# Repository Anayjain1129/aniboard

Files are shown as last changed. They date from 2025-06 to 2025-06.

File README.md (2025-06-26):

# Anay's Keyboard - Aniboard

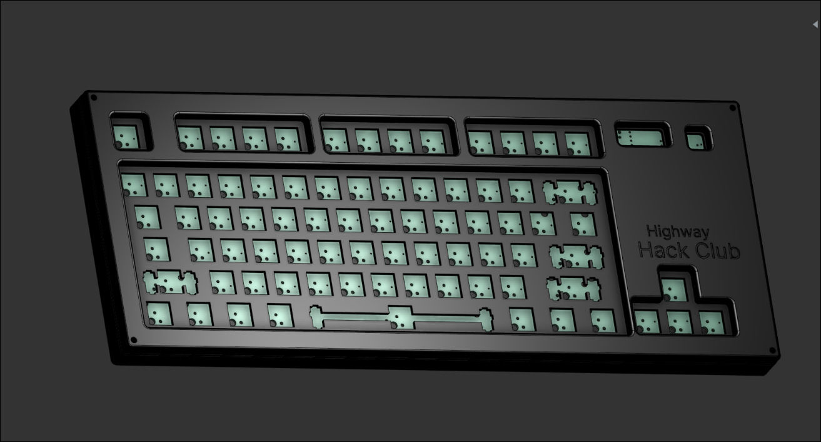
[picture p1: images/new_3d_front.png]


Made by Anay

Features:

- EC11 Rotary Encoder - For Volume, Brightness etc
- TKL Layout minus (9 keys above the arrow keys)
- 0.91" OLED for Pictures, Current Playing Media etc.
- 78x keys
- Highway & Hack Club Branded Case
- Raspberry Pico
- Personalised layout
- KMK firmware

## Info

I made this keyboard since I wanted a keyboard with the Function keys and I use use two displays so it is not actually possible to use my laptop's keyboard all the time, I made this keyboard.

I think this i s perfect keyboard for me as it has a RE and a OLED display, which can help for like increasing hte volume or decreasing, and the display can help me with the things like the spotify stuff.

Oh and it also looks very nice in my eyes. Took me more than **40 hours** making the PCB, Case and researching for the BOM. I was really so much fun to make it.

## PCB

The PCB's size is 367.100mm x 133.750mm
| Schematic                     |
| ----------------------------- |
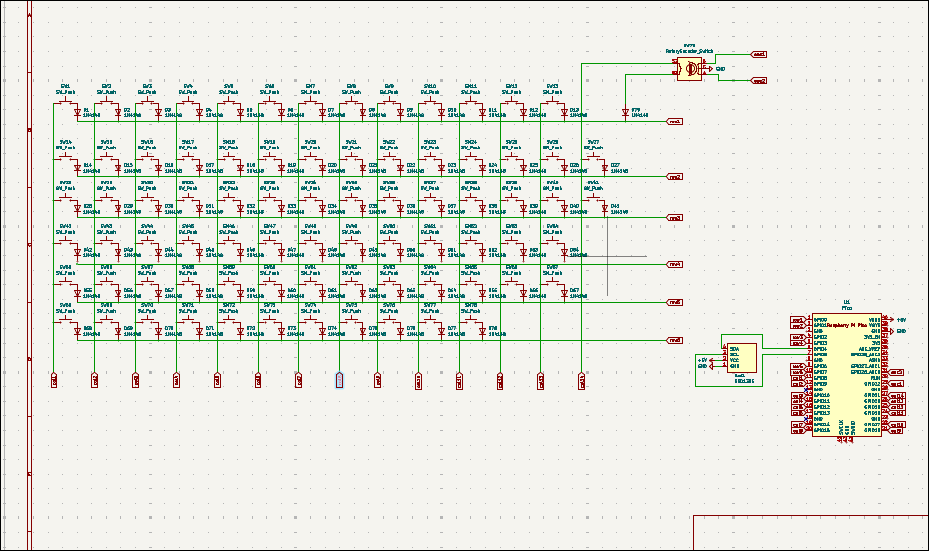
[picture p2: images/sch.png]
|  |

| Front                     |
| ------------------------- |
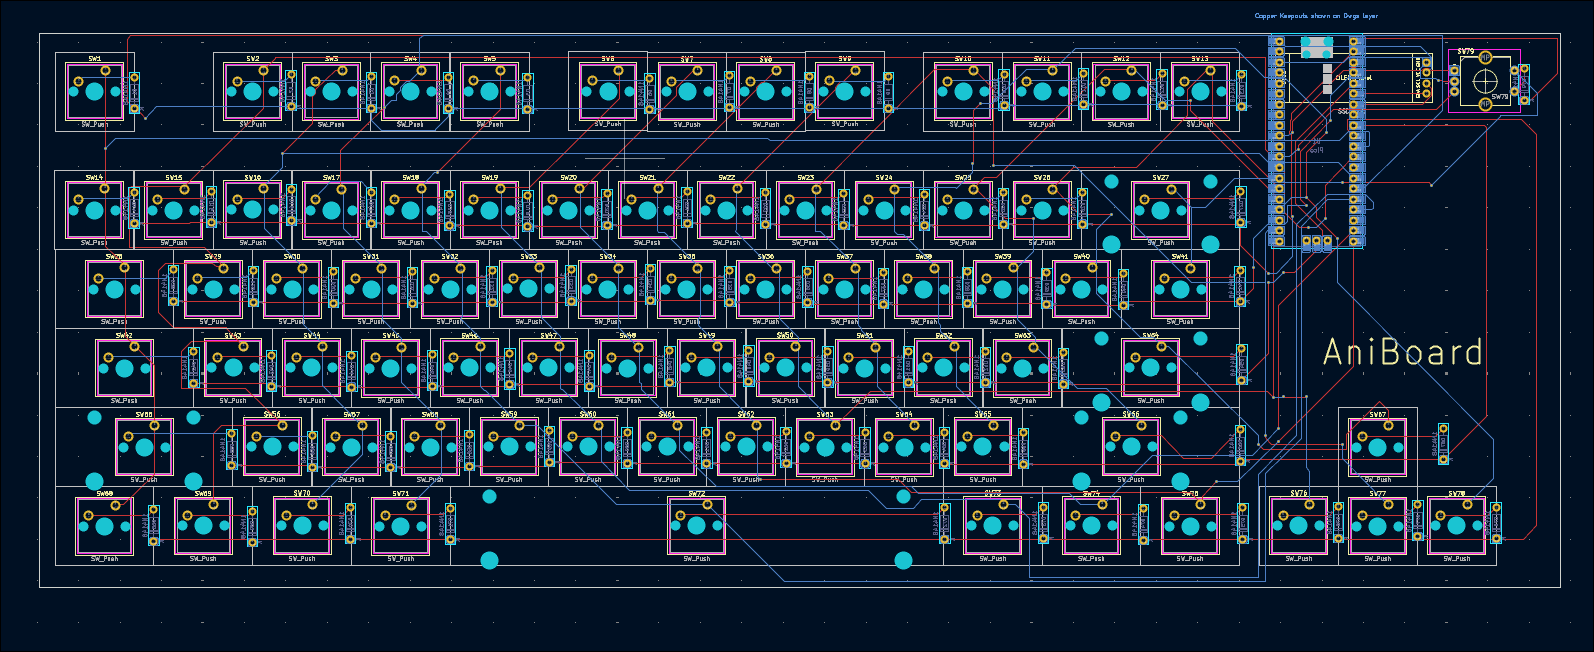
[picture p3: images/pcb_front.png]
|  |

| Back                     |
| ------------------------ |
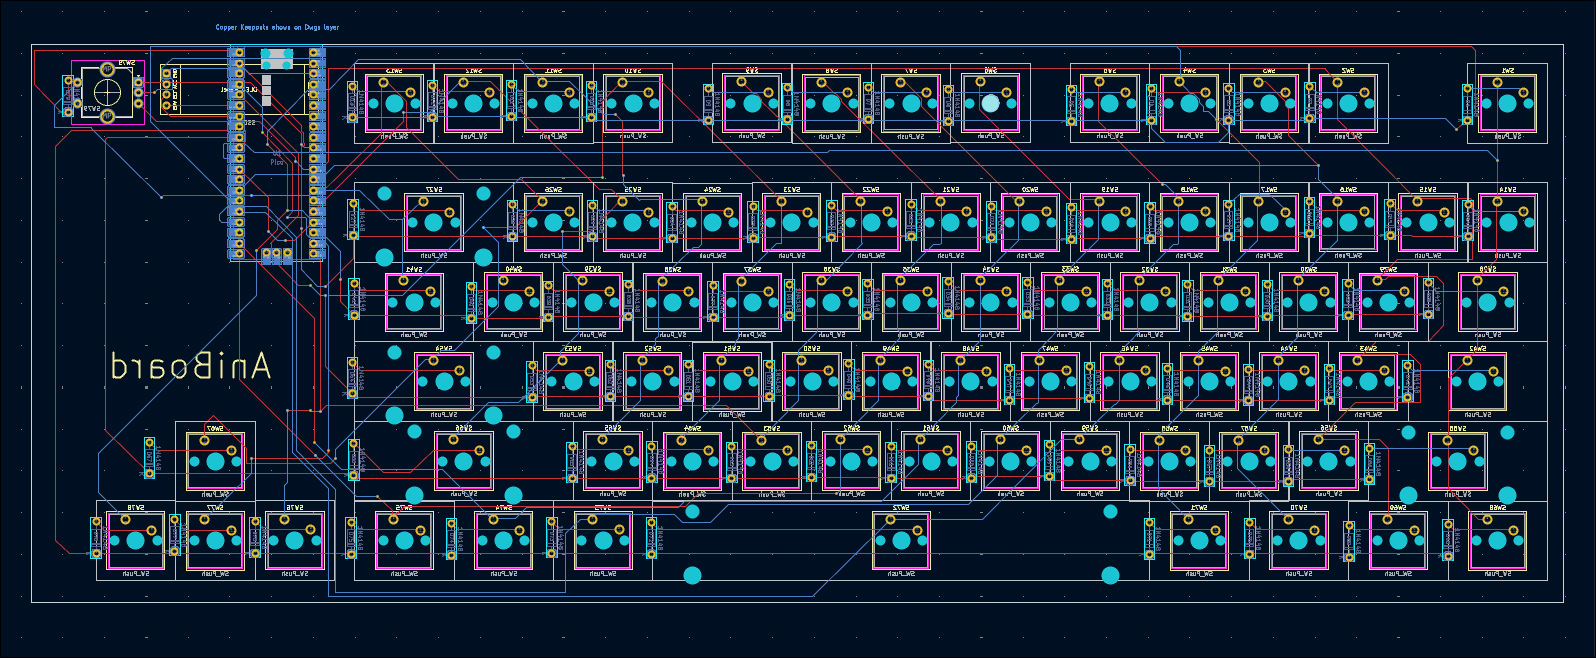
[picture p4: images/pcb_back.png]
|  |

| 3D - Front                   |
| ---------------------------- |
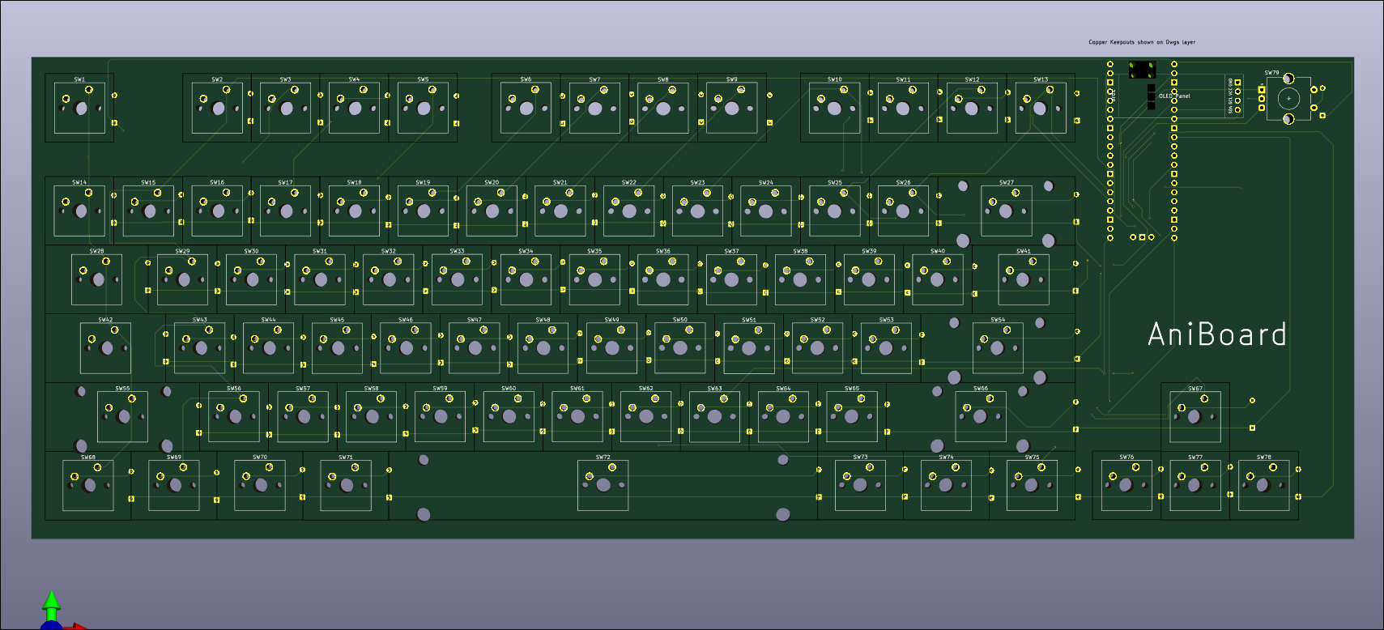
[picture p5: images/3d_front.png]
|  |

| 3D - Back                   |
| --------------------------- |
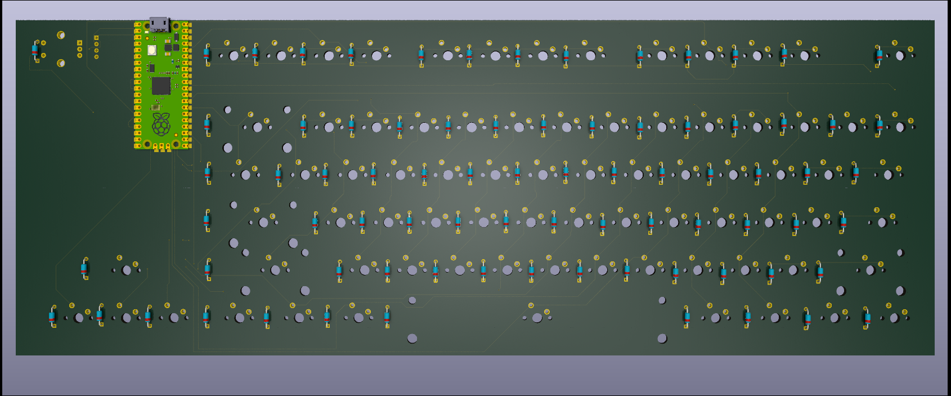
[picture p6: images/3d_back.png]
|  |

## Case

  
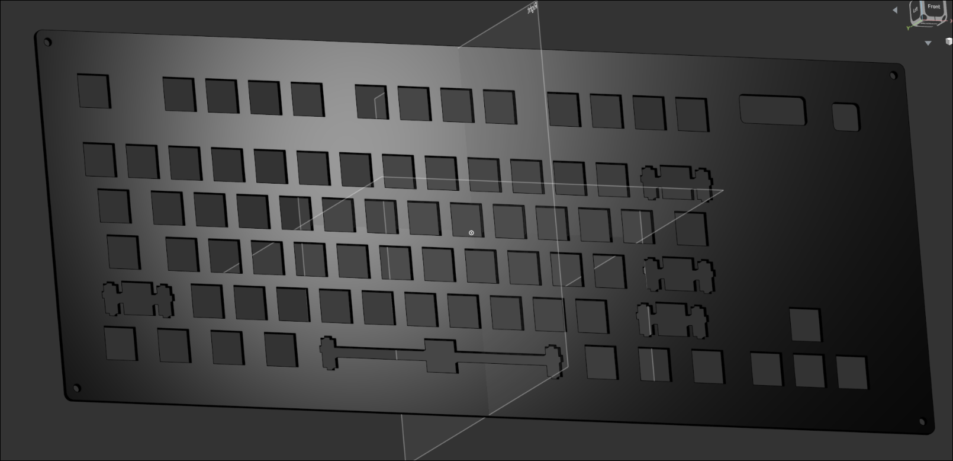
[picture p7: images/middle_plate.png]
  
  
  

I have made this case in Onshape.

there are two two parts for the case one is the top and another is the top.

# Top:

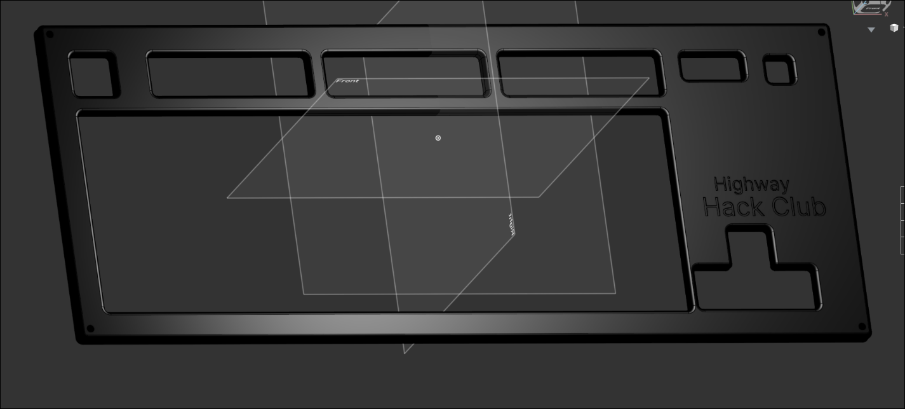
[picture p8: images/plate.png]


# Middle Plate:



# Bottom:

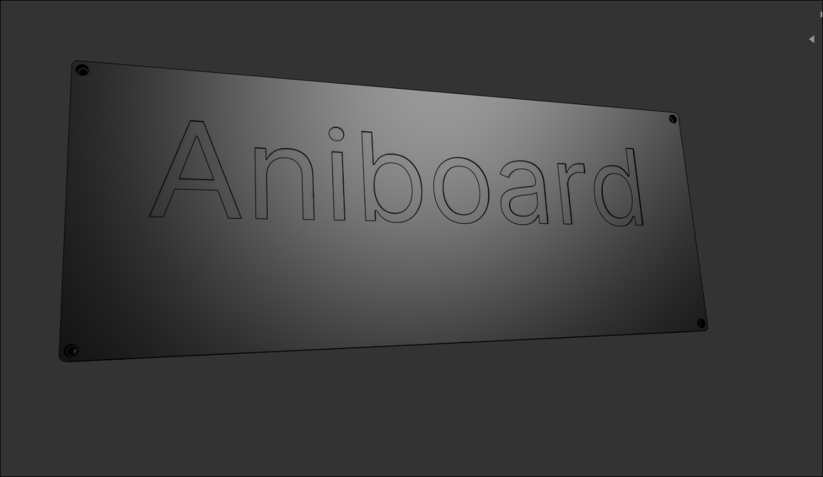
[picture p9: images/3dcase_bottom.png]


## 3D Render:




## Layout:

The Layout is a TKL (Tenkey-less) layout with some features like RE and OLED.

- removing Home, End etc island
- removing PrtSc etc island
- moving Fn key to bottom-left

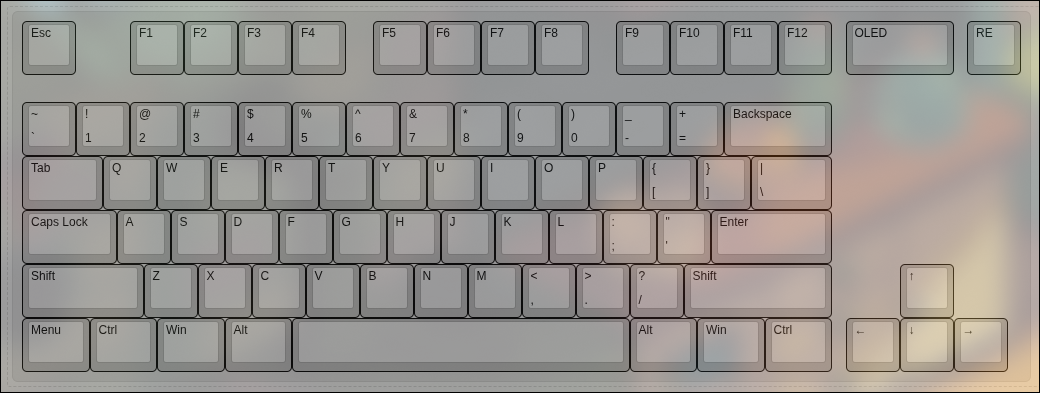
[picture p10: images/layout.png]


## BOM

| Name | Qty | Final Price - INR (USD) | Link |
| --- | --- | --- | --- |
| Gateron EF Grayish | 80  | 1560 ($18.19) | [here](https://neomacro.in/products/gateron-ef-grayish) |
| Durock Smokey Screw-In Stabilizers V2 (4+1 w/ 6.25u spacebar) | 1 | 1299 ($15.14) | [here](https://stackskb.com/store/durock-smokey-screw-in-stabilizers-v2/) |
| Cherry Profile PBT Keycaps | 1 | 1595 ($18.6) | [here](https://stackskb.com/store/veekos-gradient-keycaps-cherry-profile-135-keys) |
| Diode 1N4148 Through - Hole | 100 | 169 ($1.97) | [here](https://amzn.in/d/j3eLvoh) |
| 0.91" OLED SSD1306 | 1 | 166 ($1.92) | [here](https://amzn.in/d/3cISYEV) |
| EC11 Rotary Encoder | 2 | 178 ($2.08) | [here](https://amzn.in/d/hVRxzij) |
| M3 x 20mm Bolt | 15  | 149 ($1.73) | [here](https://amzn.in/d/8GRQWAB) |
| M3 Nuts | 8 | 100 ($1.16) | [here](https://amzn.in/d/7UQtsm8) |
| M3 x 5mm Heatset Insert | 25  | 179 ($2.09) | [here](https://amzn.in/d/ixybuAc) |
| PCB - (Black Color) | 5 | 4,923.83 ($56.87) | [here](https://hc-cdn.hel1.your-objectstorage.com/s/v3/74e4c45af47010a7cc1c4b92517cf708e2c89ca2_swappy-20250622-232946.png) |
| Raspberry Pi Pico | 1 | 449 ($5.19) | [here](http://amazon.in/Raspberry-Pi-Headers-Soldered-Micro/dp/B08WPNM7JB/ref=sr_1_2?sr=8-2) |
| Soldering Iron | 1 | 450 ($5.20) | [here](https://www.amazon.in/INDITRUST-Soldering-adjustable-Temperature-Controlled/dp/B0DP7GJ5YK/ref=sr_1_9?sr=8-9) |
| Top Case - 1 (Black "./production/CAD/top.step") | 1 | Print Legion |
| Bottom Case - 2 (Black "./production/CAD/bottom.step") | 1 | Print Legion |

## Total Pricing

The keyboard comes out to be 11217.83 INR ($129.23) When ordering all the parts I'm not including  the 3D parts because I will be getting them from Print Legion.

## Notes :-

I want all the two 3D-printed parts to be printed in black color. that includes: top.step, bottom.step .

The pricing might slightly vary due to flash sales, and dollar market trends.

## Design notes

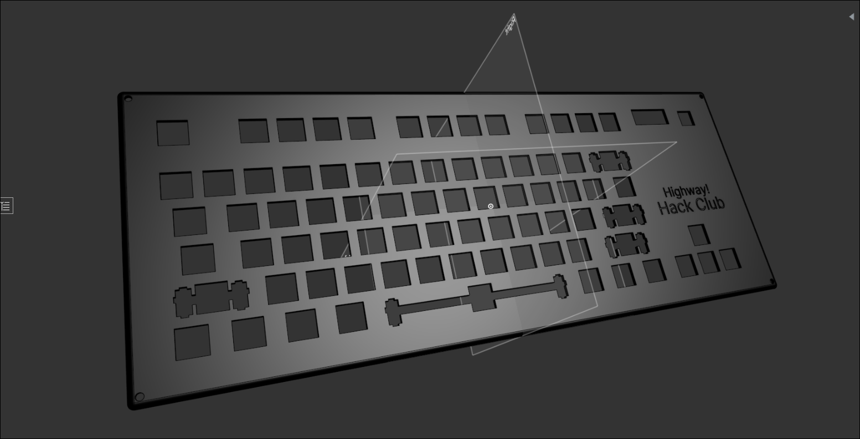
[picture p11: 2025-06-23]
images/case_top.png

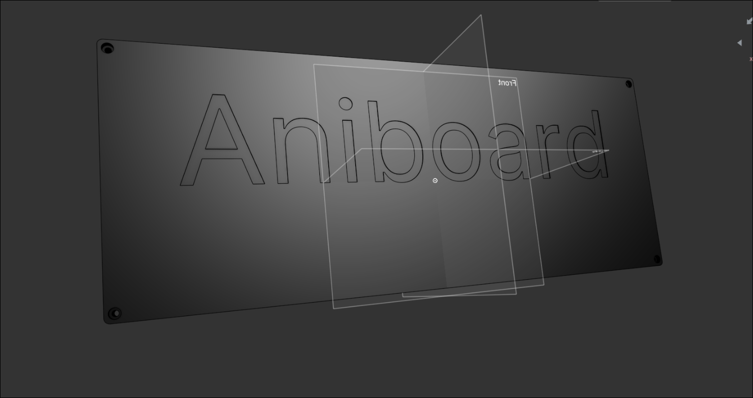
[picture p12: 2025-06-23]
images/case_bottom.png

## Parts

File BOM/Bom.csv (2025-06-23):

Name | Qty | Final Price- INR (USD) | Link
Gateron EF Grayish | 80 | 1560 ($18.19) | https://neomacro.in/products/gateron-ef-grayish
Durock Smokey Screw-In Stabilizers V2 (4+1 w/ 6.25u spacebar) | 1 | 1595 ($18.6) | https://stackskb.com/store/durock-smokey-screw-in-stabilizers-v2/
Cherry Profile PBT Keycaps | 1 | 1299 ($15.14) | https://stackskb.com/store/veekos-gradient-keycaps-cherry-profile-135-keys
Diode 1N4148 Through – Hole | 100 | 169 ($1.97) | https://amzn.in/d/j3eLvoh
0.91" OLED SSD1306 | 1 | 166 ($1.92) | https://amzn.in/d/3cISYEV
EC11 Rotary Encoder | 2 | 178 ($2.08) | https://amzn.in/d/hVRxzij
M3 x 20mm Bolt | 15 | 149 ($1.73) | https://amzn.in/d/8GRQWAB
M3 Nuts | 8 | 100 ($1.16) | https://amzn.in/d/7UQtsm8
M3 x 5mm Heatset Insert | 25 | 179 ($2.09) | https://amzn.in/d/ixybuAc
PCB - (Black Color) | 5 | 4,923.83 ($56.87) | https://hc-cdn.hel1.your-objectstorage.com/s/v3/74e4c45af47010a7cc1c4b92517cf708e2c89ca2_swappy-20250622-232946.png
Raspberry Pi Pico | 1 | 449 ($5.19) | http://amazon.in/Raspberry-Pi-Headers-Soldered-Micro/dp/B08WPNM7JB/ref=sr_1_2?sr=8-2
Soldering Iron | 1 | 450 ($5.20) | https://www.amazon.in/INDITRUST-Soldering-adjustable-Temperature-Controlled/dp/B0DP7GJ5YK
Top Case - 1 (Black "./production/top.step") | 1 | Print Legion
Bottom Case - 2 (Black "./production/bottom.step") | 1 | Print Legion

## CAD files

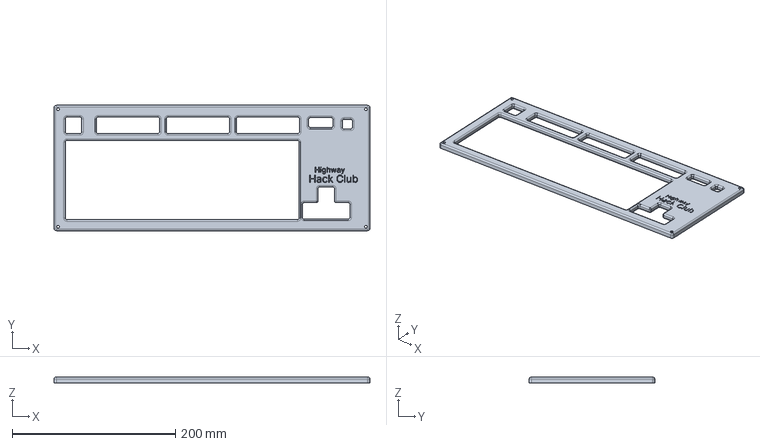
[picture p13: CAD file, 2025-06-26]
CAD/Top.step
387.1 x 153.8 x 7.00 mm

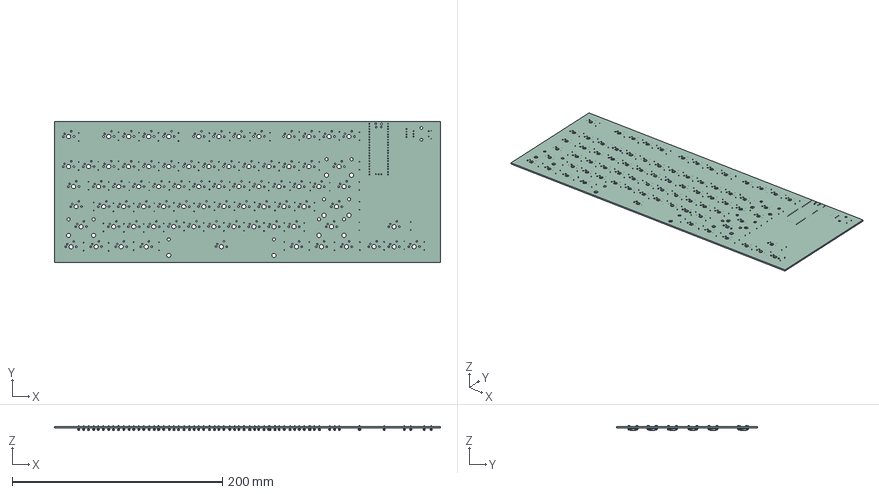
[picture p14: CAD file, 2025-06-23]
PCB/hackboard.step
367.1 x 133.7 x 5.01 mm
D_DO-35_SOD27_P7.62mm_Horizontal x 79
Pico
hackboard_PCB

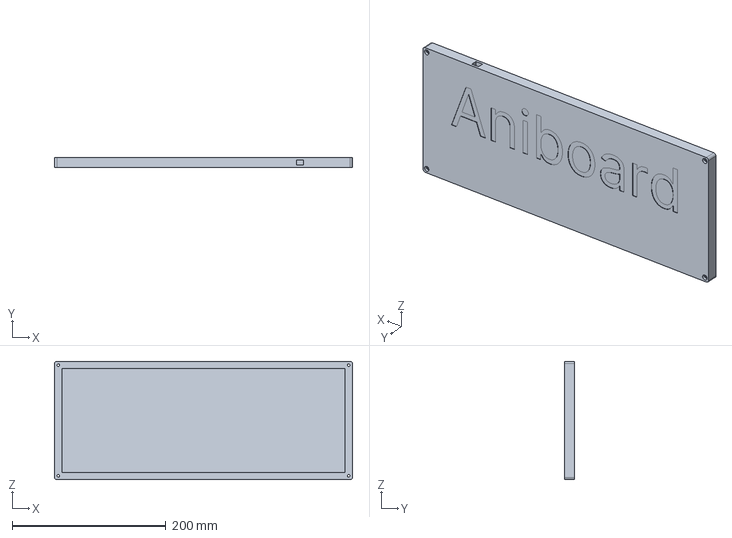
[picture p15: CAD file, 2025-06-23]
Production/CAD/bottom.step
387.1 x 13.0 x 153.8 mm

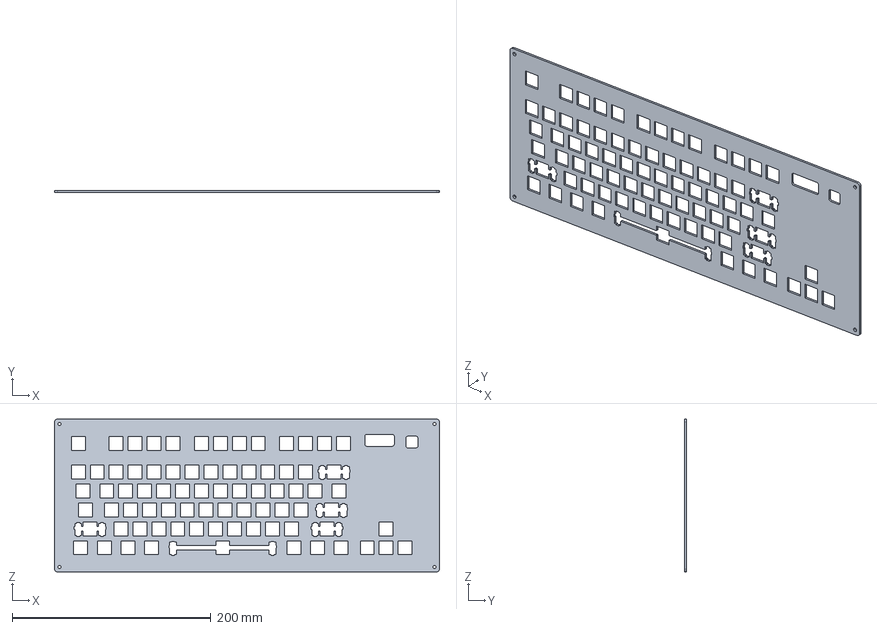
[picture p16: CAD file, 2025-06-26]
CAD/Middle Plate.step
387.1 x 2.00 x 153.8 mm

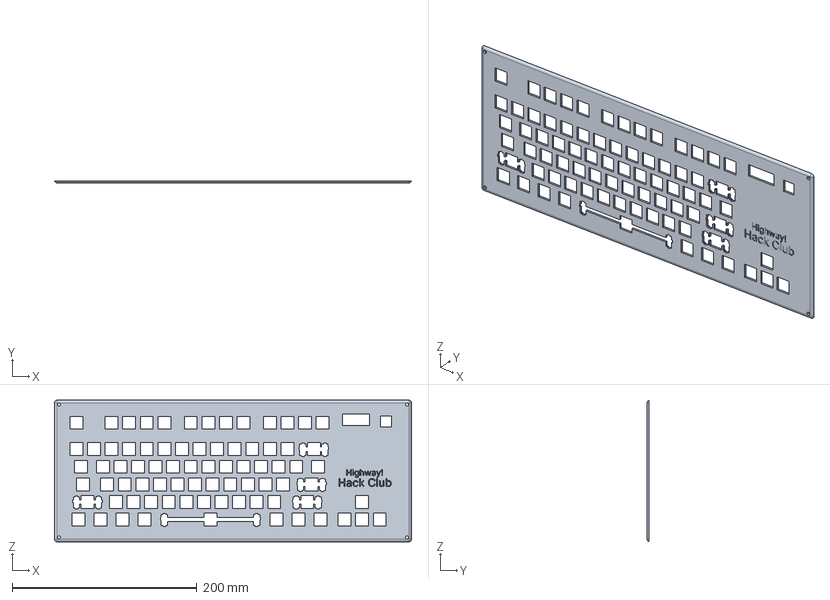
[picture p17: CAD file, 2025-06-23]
Production/CAD/top.step
386.8 x 2.00 x 153.4 mm

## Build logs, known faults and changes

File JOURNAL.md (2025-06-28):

---
title: "AniiBoard"
author: "@Anayjain1129"
description: "It is fully custom keyboard"
created_at: "2025-06-11"
---

**Total time spent so far: 42hrs**

## 11th June: Research
> Watched a lot of youtube tuts and read so many documents to get a basic idea and all of what i wanted make and make my keyboard look like.
> Decided to go with 75% Mechanical Keyboard layout (with 10 less keys) and some customisations.

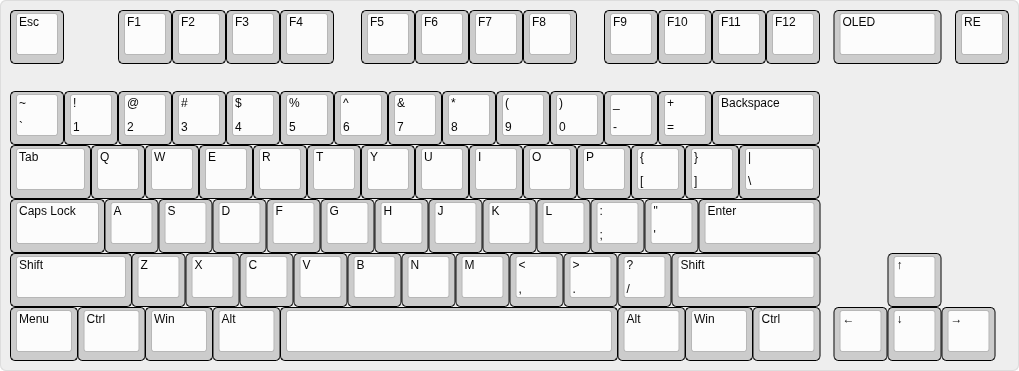
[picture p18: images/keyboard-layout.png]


> It is gonna have a a `EC11 Rotary Encoder`, and a `0.91" OLED SSD1306` and is gonna use `Rasberry pi Pico` for it's micro controller.

**Time Spent: 4hrs**

## 12th June: Started with sch
>I had done direct wiring before but never done the matrix wiring so first I learned how to do matrix wiring and how to use global Labels.



>did some basic wiring, after an hour of research wired everything to mcu.

**Time Spent: 5hrs**

## 13th June: Started with sch
>Completed the SCH and then moved on to PCB, Seriously It was pain, first I had to figureout how i can make the sizes of stwitches big and did all of them manually.
>Finnaly aligned all the switches and everything like the OLED and Encoder, the only things left are diodes

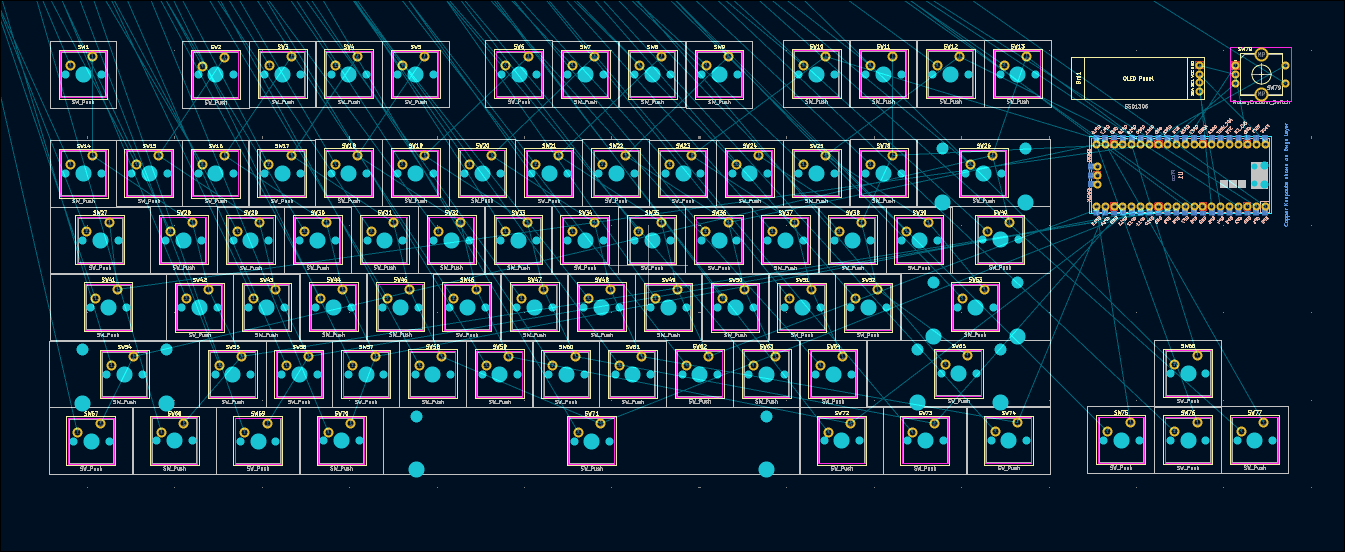
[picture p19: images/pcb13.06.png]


>did some basic wiring, after an hour of research wired everything to mcu.

**Time Spent: 5hrs**

## 14th June: Started with PCB
>aligned everything as I wanted or we can say according to my layout, it was kinda messy thig but finally after 4 hours did it.
>Faced challenges withe pcb part, as i was using matrix, and its my first time working with it so yea it was kinda hard and faced issues like the component placement grid, finding where to put the diodes

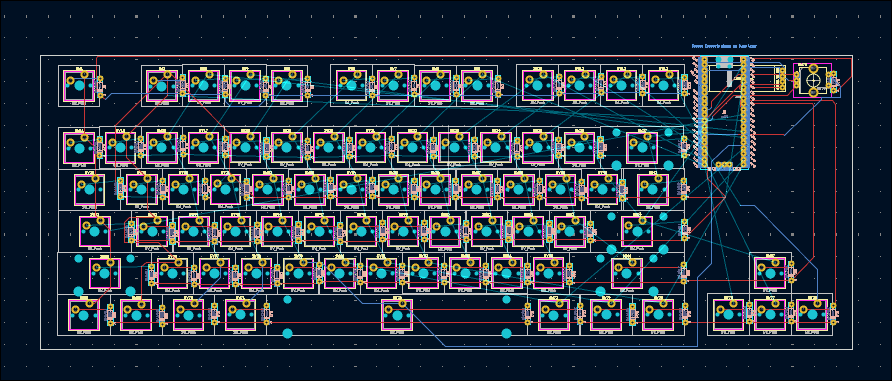
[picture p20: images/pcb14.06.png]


>at last Done my component placement 

**Time Spent: 6hrs**

## 15th June:Done by PCB 
>Finally after 5hr I'm completely done with the PCB connected everything and named my board and also added orpheus at the bottom.

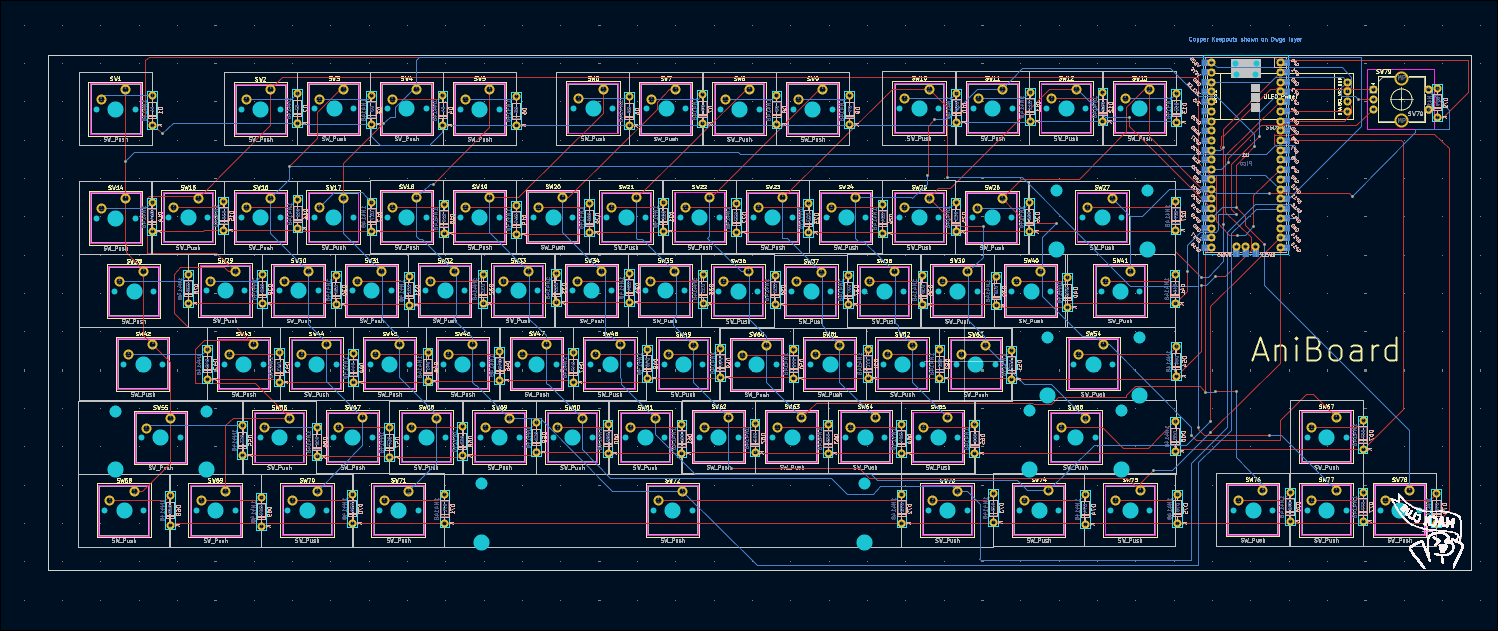
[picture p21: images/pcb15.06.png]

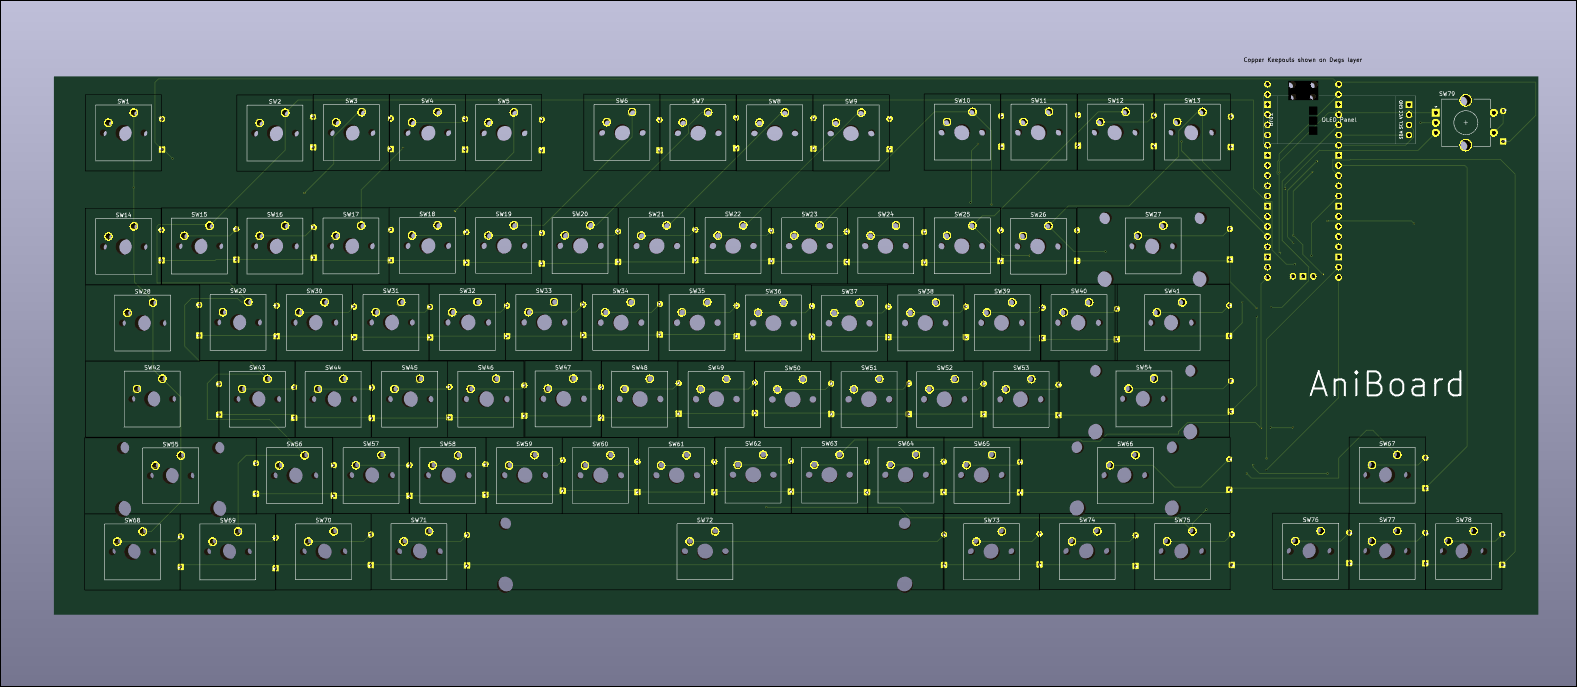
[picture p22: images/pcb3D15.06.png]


**Time Spent: 4hrs**

## 16th June:Started With CAD(3D)
>First I tohught it is gonna be easy I thought I can like use the guide of hackpad to make it, it is alot different, So made the bottom part but gonna make it again cause I don't think it is upto the mark.

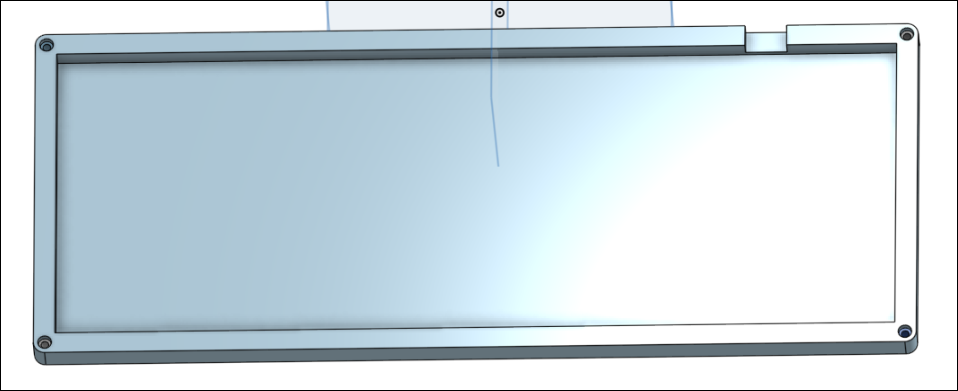
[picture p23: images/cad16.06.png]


**Time Spent: 2hrs**

## 18th June: Working on Case
>Working on CAD Gotta sleep now been working on it for like 6 hous the above case wasn't good enough so i'm working on new one the images are below.
>Really had issues with OnShape but still made it out.

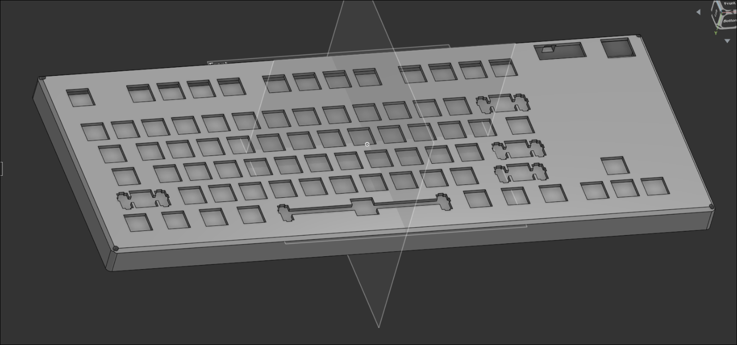
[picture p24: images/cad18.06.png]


**Time Spent: 6hrs**

## 21st June: Completed by the case or the 3D part
>faced alot of issues, like with onshpae but finally I made through and I love the fact that I hate onshape but still I'm loving onshape
>Made so much progress today, now I'm going to work on the firmware.
>>and all of sudden I just love highwaying, A very very big thanks to highway team.

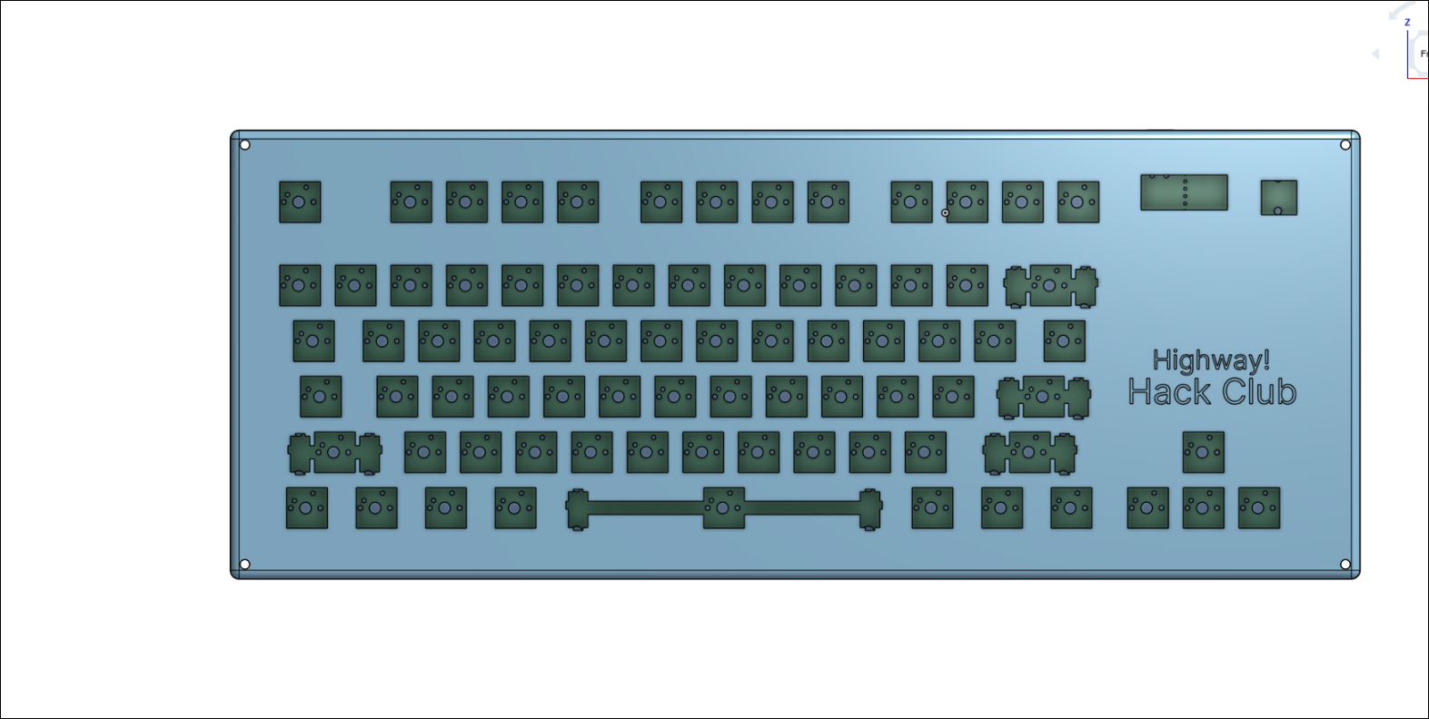
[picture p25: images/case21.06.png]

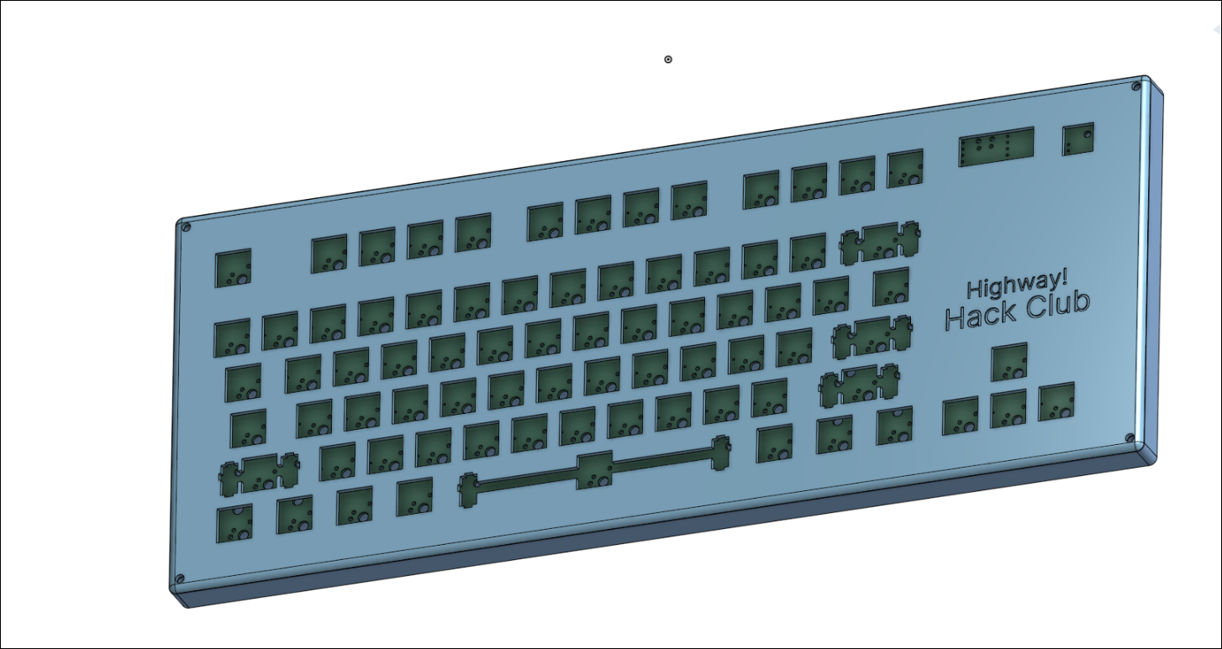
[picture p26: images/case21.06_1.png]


**Time Spent: 4hrs**

## 22nd June: Completed by the firmware
I did some gpting since its very hard to make the firmware without having the parts with me 😭. and BOOM I had a firmware, I made a tiny functions like for Encoder and OLED display.

**Time Spent: 2hrs**

## 26nd June: Made the changes that were requested
Made the changes in the Cad part and now my case looks so much good


**Time Spent: 4hrs**

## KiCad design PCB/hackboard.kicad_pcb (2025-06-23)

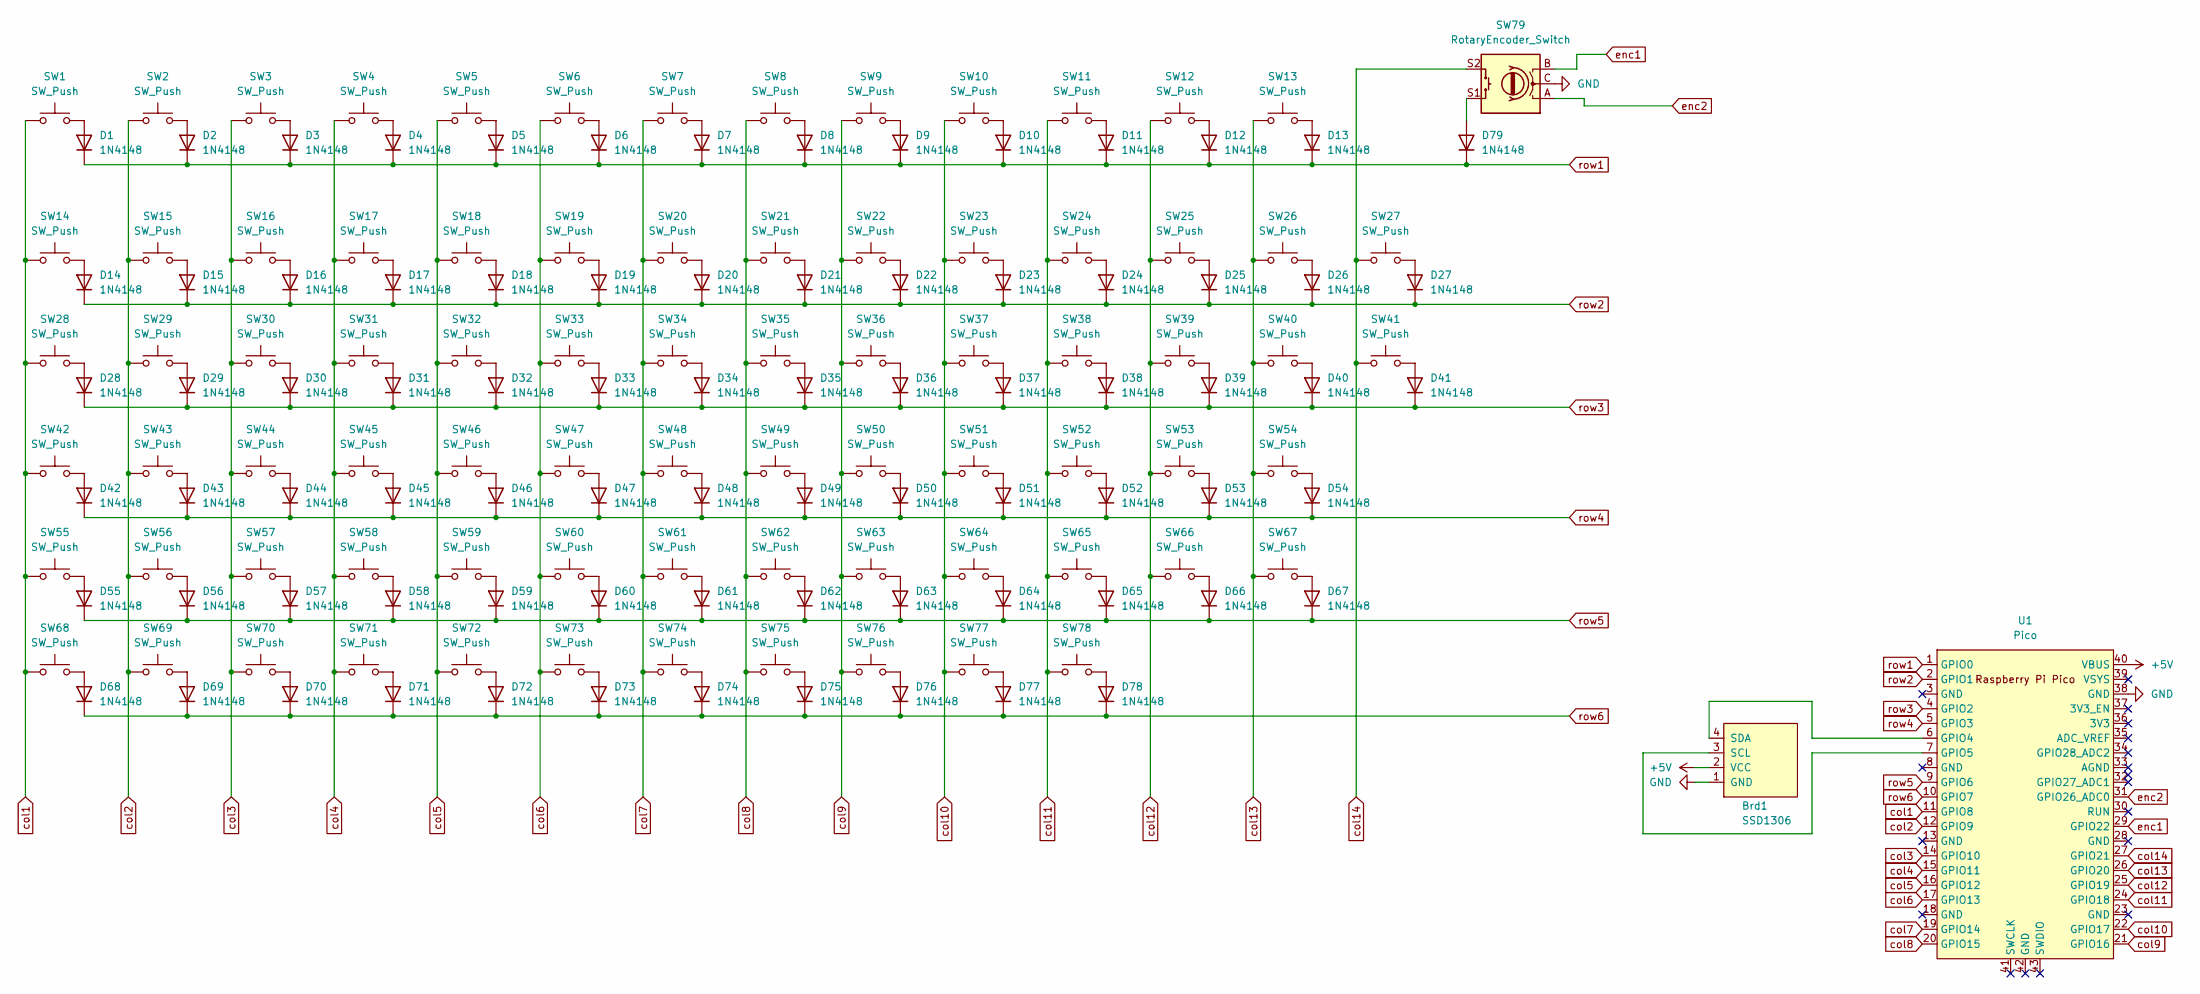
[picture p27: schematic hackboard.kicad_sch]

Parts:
Brd1: SSD1306; SSD1306-0.91-OLED-4pin-128x32
D1, D2, D3, D4, D5, D6, D7, D8, D9, D10, D11, D12, D13, D14, D15, D16, D17, D18, D19, D20, D21, D22, D23, D24, D25, D26, D27, D28, D29, D30, D31, D32, D33, D34, D35, D36, D37, D38, D39, D40, D41, D42, D43, D44, D45, D46, D47, D48, D49, D50, D51, D52, D53, D54, D55, D56, D57, D58, D59, D60, D61, D62, D63, D64, D65, D66, D67, D68, D69, D70, D71, D72, D73, D74, D75, D76, D77, D78, D79: 1N4148; D_DO-35_SOD27_P7.62mm_Horizontal
SW1, SW2, SW3, SW4, SW5, SW6, SW7, SW8, SW9, SW10, SW11, SW12, SW13, SW14, SW15, SW16, SW17, SW18, SW19, SW20, SW21, SW22, SW23, SW24, SW25, SW26, SW29, SW30, SW31, SW32, SW33, SW34, SW35, SW36, SW37, SW38, SW39, SW40, SW43, SW44, SW45, SW46, SW47, SW48, SW49, SW50, SW51, SW52, SW53, SW56, SW57, SW58, SW59, SW60, SW61, SW62, SW63, SW64, SW65, SW67, SW76, SW77, SW78: SW_Push; SW_Cherry_MX_1.00u_PCB
SW27: SW_Push; SW_Cherry_MX_2.00u_PCB
SW28, SW41: SW_Push; SW_Cherry_MX_1.50u_PCB
SW42: SW_Push; SW_Cherry_MX_1.75u_PCB
SW54, SW55: SW_Push; SW_Cherry_MX_2.25u_PCB
SW66: SW_Push; SW_Cherry_MX_2.75u_PCB
SW68, SW69, SW70, SW71, SW73, SW74, SW75: SW_Push; SW_Cherry_MX_1.25u_PCB
SW72: SW_Push; SW_Cherry_MX_6.25u_PCB
SW79: RotaryEncoder_Switch; RotaryEncoder_Alps_EC11E-Switch_Vertical_H20mm_CircularMoun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
U1: Pico; RPi_Pico_SMD_TH

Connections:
+5V: Brd1.2 (VCC), U1.40 (VBUS)
GND: Brd1.1 (GND), SW79.C, U1.38 (GND)
unnamed: Brd1.3 (SCL), U1.7 (GPIO5)
unnamed: Brd1.4 (SDA), U1.6 (GPIO4)
unnamed: D1.2 (A), SW1.2
unnamed: D2.2 (A), SW2.2
unnamed: D3.2 (A), SW3.2
unnamed: D4.2 (A), SW4.2
unnamed: D5.2 (A), SW5.2
unnamed: D6.2 (A), SW6.2
unnamed: D7.2 (A), SW7.2
unnamed: D8.2 (A), SW8.2
unnamed: D9.2 (A), SW9.2
unnamed: D10.2 (A), SW10.2
unnamed: D11.2 (A), SW11.2
unnamed: D12.2 (A), SW12.2
unnamed: D13.2 (A), SW13.2
unnamed: D14.2 (A), SW14.2
unnamed: D15.2 (A), SW15.2
unnamed: D16.2 (A), SW16.2
unnamed: D17.2 (A), SW17.2
unnamed: D18.2 (A), SW18.2
unnamed: D19.2 (A), SW19.2
unnamed: D20.2 (A), SW20.2
unnamed: D21.2 (A), SW21.2
unnamed: D22.2 (A), SW22.2
unnamed: D23.2 (A), SW23.2
unnamed: D24.2 (A), SW24.2
unnamed: D25.2 (A), SW25.2
unnamed: D26.2 (A), SW26.2
unnamed: D27.2 (A), SW27.2
unnamed: D28.2 (A), SW28.2
unnamed: D29.2 (A), SW29.2
unnamed: D30.2 (A), SW30.2
unnamed: D31.2 (A), SW31.2
unnamed: D32.2 (A), SW32.2
unnamed: D33.2 (A), SW33.2
unnamed: D34.2 (A), SW34.2
unnamed: D35.2 (A), SW35.2
unnamed: D36.2 (A), SW36.2
unnamed: D37.2 (A), SW37.2
unnamed: D38.2 (A), SW38.2
unnamed: D39.2 (A), SW39.2
unnamed: D40.2 (A), SW40.2
unnamed: D41.2 (A), SW41.2
unnamed: D42.2 (A), SW42.2
unnamed: D43.2 (A), SW43.2
unnamed: D44.2 (A), SW44.2
unnamed: D45.2 (A), SW45.2
unnamed: D46.2 (A), SW46.2
unnamed: D47.2 (A), SW47.2
unnamed: D48.2 (A), SW48.2
unnamed: D49.2 (A), SW49.2
unnamed: D50.2 (A), SW50.2
unnamed: D51.2 (A), SW51.2
unnamed: D52.2 (A), SW52.2
unnamed: D53.2 (A), SW53.2
unnamed: D54.2 (A), SW54.2
unnamed: D55.2 (A), SW55.2
unnamed: D56.2 (A), SW56.2
unnamed: D57.2 (A), SW57.2
unnamed: D58.2 (A), SW58.2
unnamed: D59.2 (A), SW59.2
unnamed: D60.2 (A), SW60.2
unnamed: D61.2 (A), SW61.2
unnamed: D62.2 (A), SW62.2
unnamed: D63.2 (A), SW63.2
unnamed: D64.2 (A), SW64.2
unnamed: D65.2 (A), SW65.2
unnamed: D66.2 (A), SW66.2
unnamed: D67.2 (A), SW67.2
unnamed: D68.2 (A), SW68.2
unnamed: D69.2 (A), SW69.2
unnamed: D70.2 (A), SW70.2
unnamed: D71.2 (A), SW71.2
unnamed: D72.2 (A), SW72.2
unnamed: D73.2 (A), SW73.2
unnamed: D74.2 (A), SW74.2
unnamed: D75.2 (A), SW75.2
unnamed: D76.2 (A), SW76.2
unnamed: D77.2 (A), SW77.2
unnamed: D78.2 (A), SW78.2
unnamed: D79.2 (A), SW79.S1
col1: SW1.1, SW14.1, SW28.1, SW42.1, SW55.1, SW68.1, U1.11 (GPIO8)
col2: SW2.1, SW15.1, SW29.1, SW43.1, SW56.1, SW69.1, U1.12 (GPIO9)
col3: SW3.1, SW16.1, SW30.1, SW44.1, SW57.1, SW70.1, U1.14 (GPIO10)
col4: SW4.1, SW17.1, SW31.1, SW45.1, SW58.1, SW71.1, U1.15 (GPIO11)
col5: SW5.1, SW18.1, SW32.1, SW46.1, SW59.1, SW72.1, U1.16 (GPIO12)
col6: SW6.1, SW19.1, SW33.1, SW47.1, SW60.1, SW73.1, U1.17 (GPIO13)
col7: SW7.1, SW20.1, SW34.1, SW48.1, SW61.1, SW74.1, U1.19 (GPIO14)
col8: SW8.1, SW21.1, SW35.1, SW49.1, SW62.1, SW75.1, U1.20 (GPIO15)
col9: SW9.1, SW22.1, SW36.1, SW50.1, SW63.1, SW76.1, U1.21 (GPIO16)
col10: SW10.1, SW23.1, SW37.1, SW51.1, SW64.1, SW77.1, U1.22 (GPIO17)
col11: SW11.1, SW24.1, SW38.1, SW52.1, SW65.1, SW78.1, U1.24 (GPIO18)
col12: SW12.1, SW25.1, SW39.1, SW53.1, SW66.1, U1.25 (GPIO19)
col13: SW13.1, SW26.1, SW40.1, SW54.1, SW67.1, U1.26 (GPIO20)
col14: SW27.1, SW41.1, SW79.S2, U1.27 (GPIO21)
enc1: SW79.B, U1.29 (GPIO22)
enc2: SW79.A, U1.31 (GPIO26_ADC0)
row1: D1.1 (K), D2.1 (K), D3.1 (K), D4.1 (K), D5.1 (K), D6.1 (K), D7.1 (K), D8.1 (K), D9.1 (K), D10.1 (K), D11.1 (K), D12.1 (K), D13.1 (K), D79.1 (K), U1.1 (GPIO0)
row2: D14.1 (K), D15.1 (K), D16.1 (K), D17.1 (K), D18.1 (K), D19.1 (K), D20.1 (K), D21.1 (K), D22.1 (K), D23.1 (K), D24.1 (K), D25.1 (K), D26.1 (K), D27.1 (K), U1.2 (GPIO1)
row3: D28.1 (K), D29.1 (K), D30.1 (K), D31.1 (K), D32.1 (K), D33.1 (K), D34.1 (K), D35.1 (K), D36.1 (K), D37.1 (K), D38.1 (K), D39.1 (K), D40.1 (K), D41.1 (K), U1.4 (GPIO2)
row4: D42.1 (K), D43.1 (K), D44.1 (K), D45.1 (K), D46.1 (K), D47.1 (K), D48.1 (K), D49.1 (K), D50.1 (K), D51.1 (K), D52.1 (K), D53.1 (K), D54.1 (K), U1.5 (GPIO3)
row5: D55.1 (K), D56.1 (K), D57.1 (K), D58.1 (K), D59.1 (K), D60.1 (K), D61.1 (K), D62.1 (K), D63.1 (K), D64.1 (K), D65.1 (K), D66.1 (K), D67.1 (K), U1.9 (GPIO6)
row6: D68.1 (K), D69.1 (K), D70.1 (K), D71.1 (K), D72.1 (K), D73.1 (K), D74.1 (K), D75.1 (K), D76.1 (K), D77.1 (K), D78.1 (K), U1.10 (GPIO7)

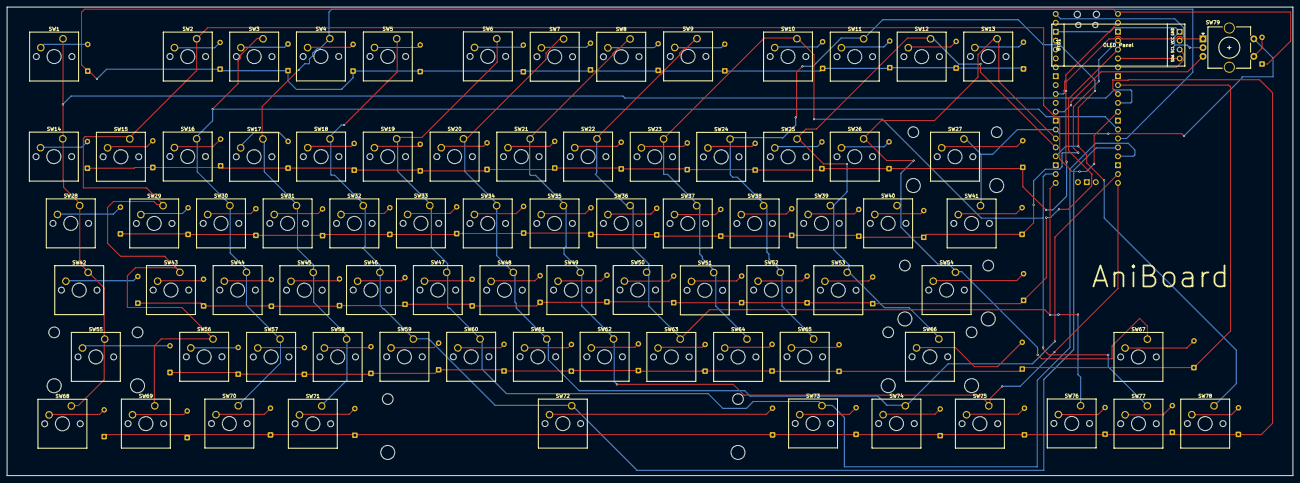
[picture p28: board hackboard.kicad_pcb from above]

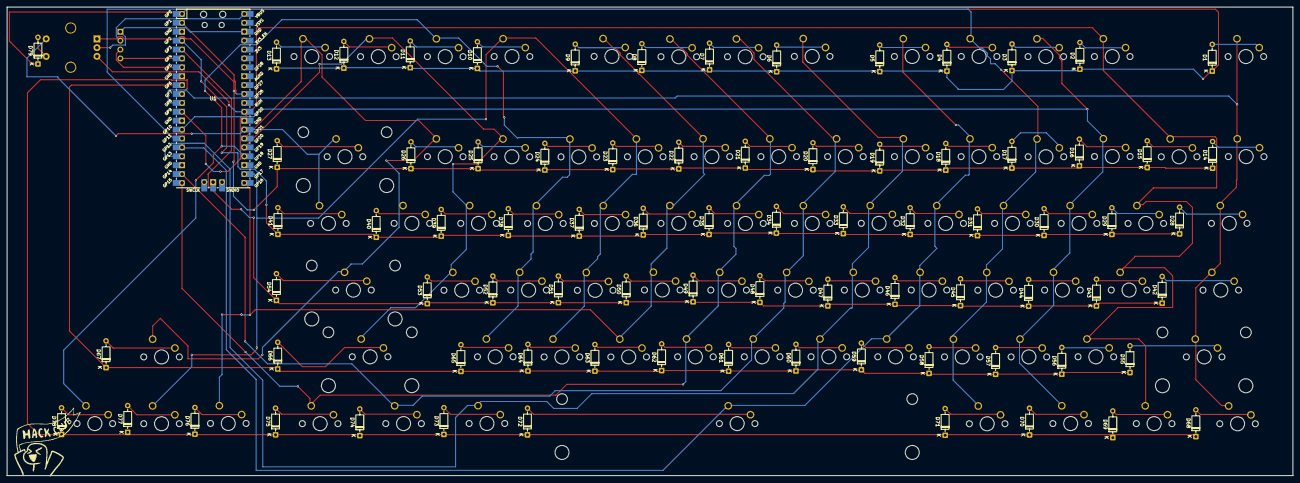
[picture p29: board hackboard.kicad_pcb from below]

Board: 2 copper layers, 367.1 x 133.7 mm, 161 parts (81 on the bottom side), 105 nets.

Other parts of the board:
Orpheus: LOGO
